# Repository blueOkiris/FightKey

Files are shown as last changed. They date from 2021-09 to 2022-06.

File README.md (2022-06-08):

# Fight Key

## Description

A keyboard-based fight stick

Image of New Physical Fight Key

Version 1:

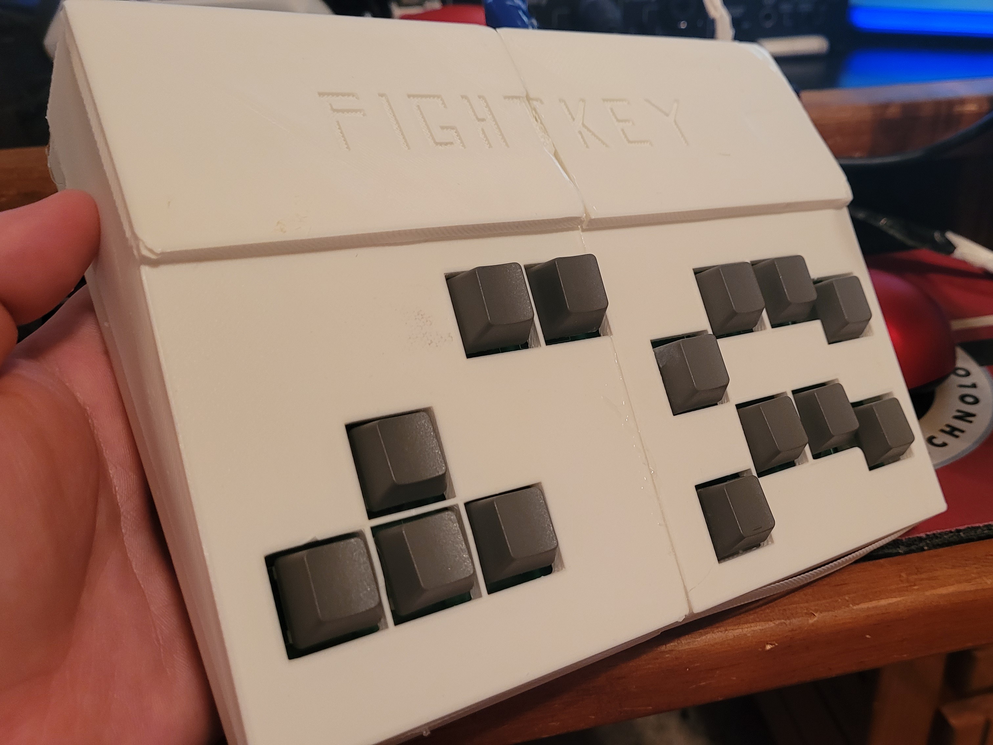
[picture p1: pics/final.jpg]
Image of Physical Fight Key


## Subdirectories

 - pcb - Fight Key KiCAD PCB project

 - pico - Code to upload to the pico within the Fight Key

 - enclosure - model for the 3D printed case for the Fight Key

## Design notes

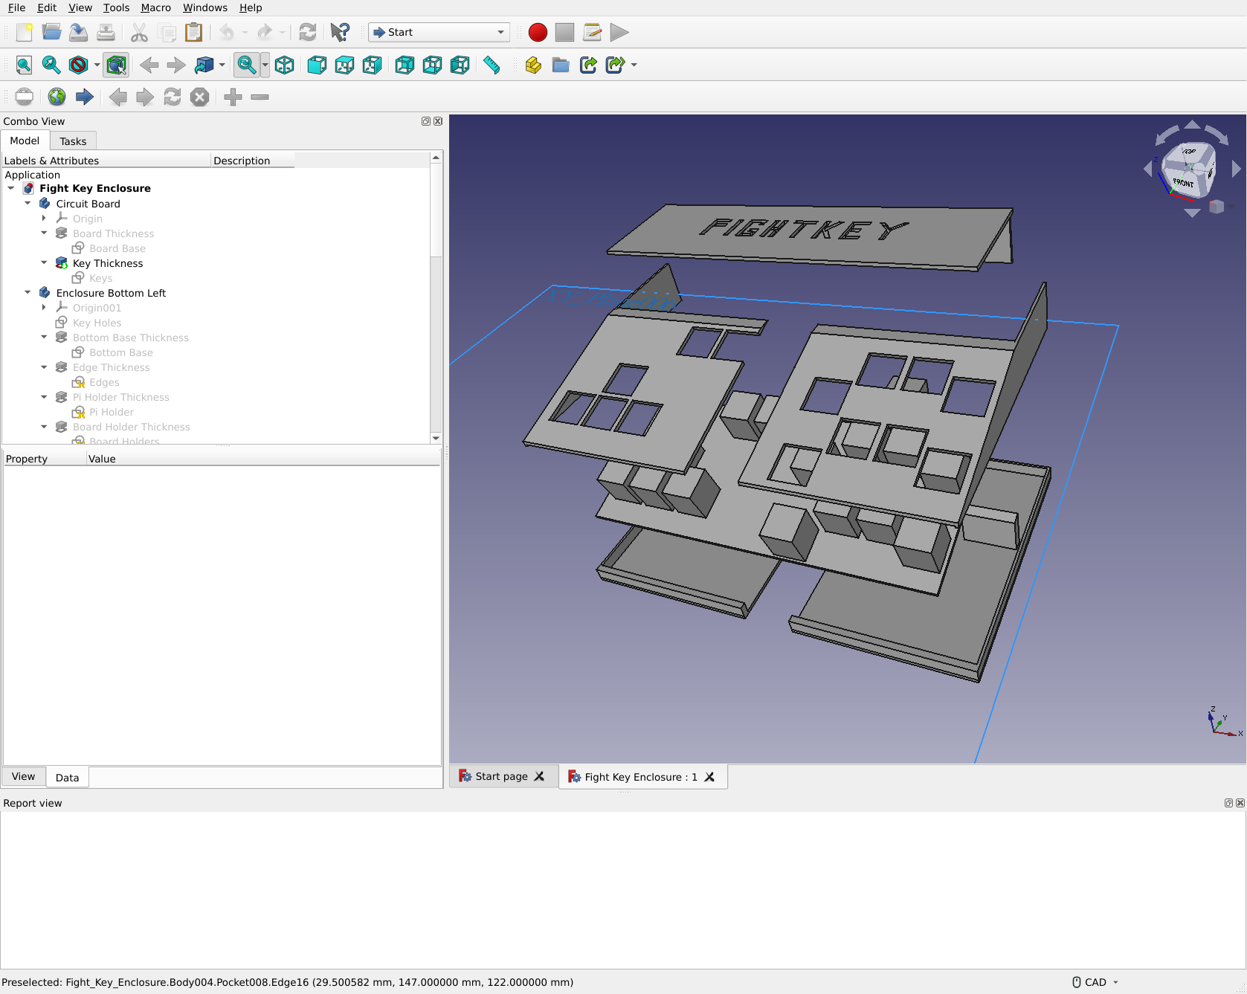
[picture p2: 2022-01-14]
pics/fight-key-model.png

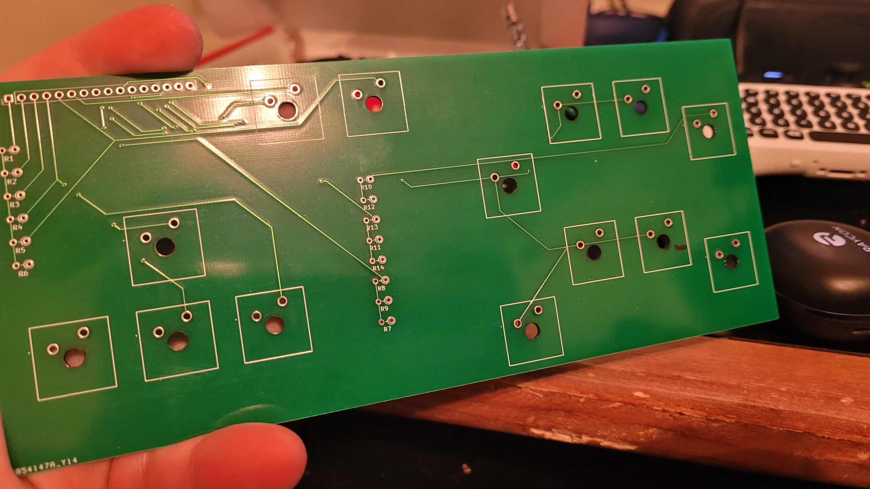
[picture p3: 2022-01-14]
pics/board.png

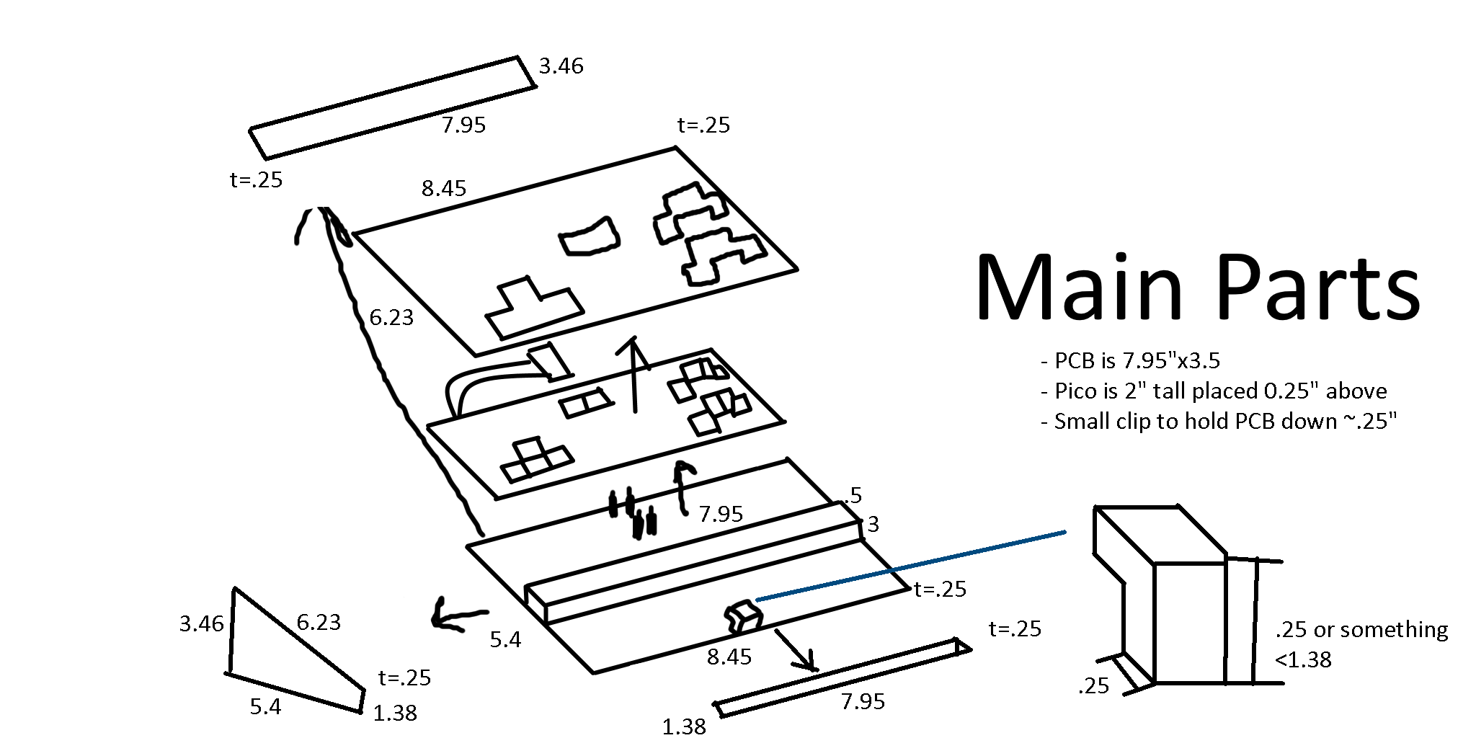
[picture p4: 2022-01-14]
enclosure/basic-idea.png

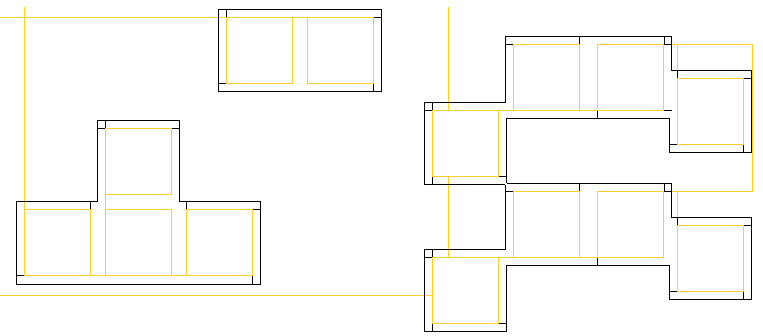
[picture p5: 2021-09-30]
enclosure/cut-out.png

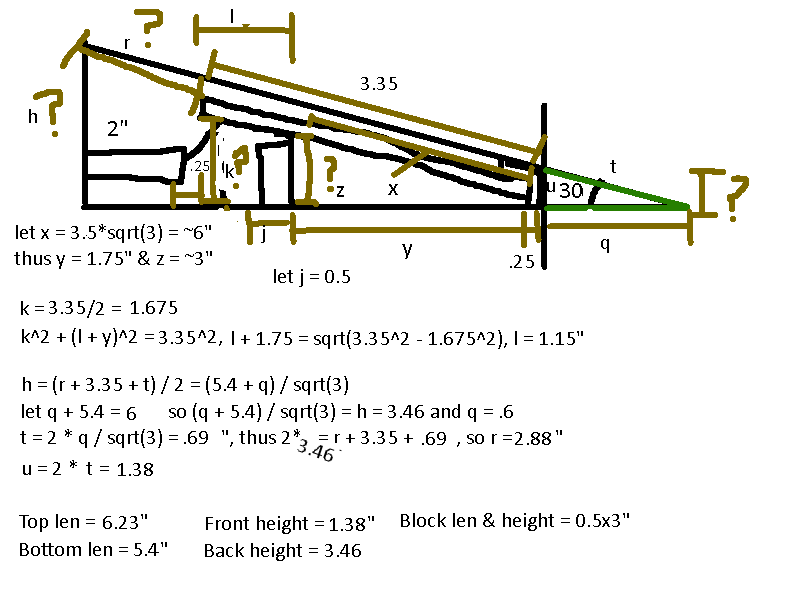
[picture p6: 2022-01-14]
enclosure/trig.png

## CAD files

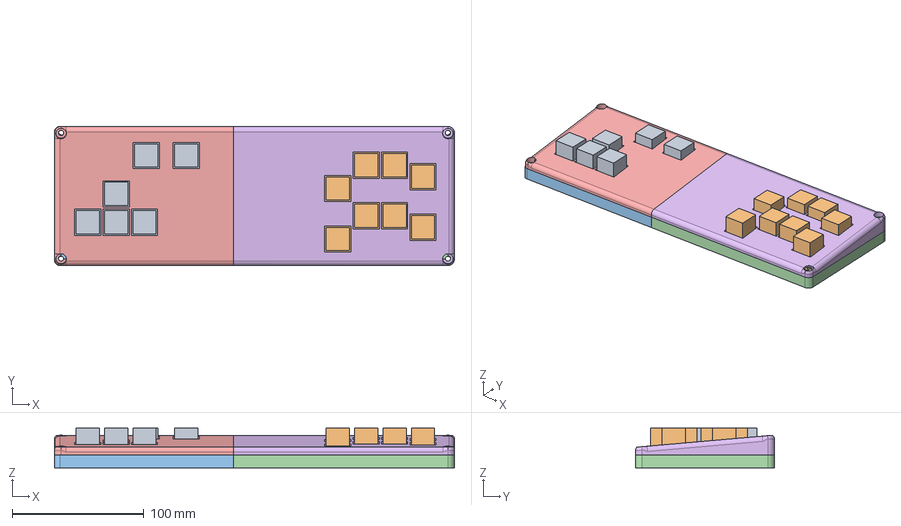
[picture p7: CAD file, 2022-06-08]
enclosure/Fight Key Enclosure.FCStd
304.0 x 105.7 x 30.3 mm
Left PCB Ref
Right PCB Ref
Left Enc Base
Right Enc Base
Left Enc Top
Right Enc Top

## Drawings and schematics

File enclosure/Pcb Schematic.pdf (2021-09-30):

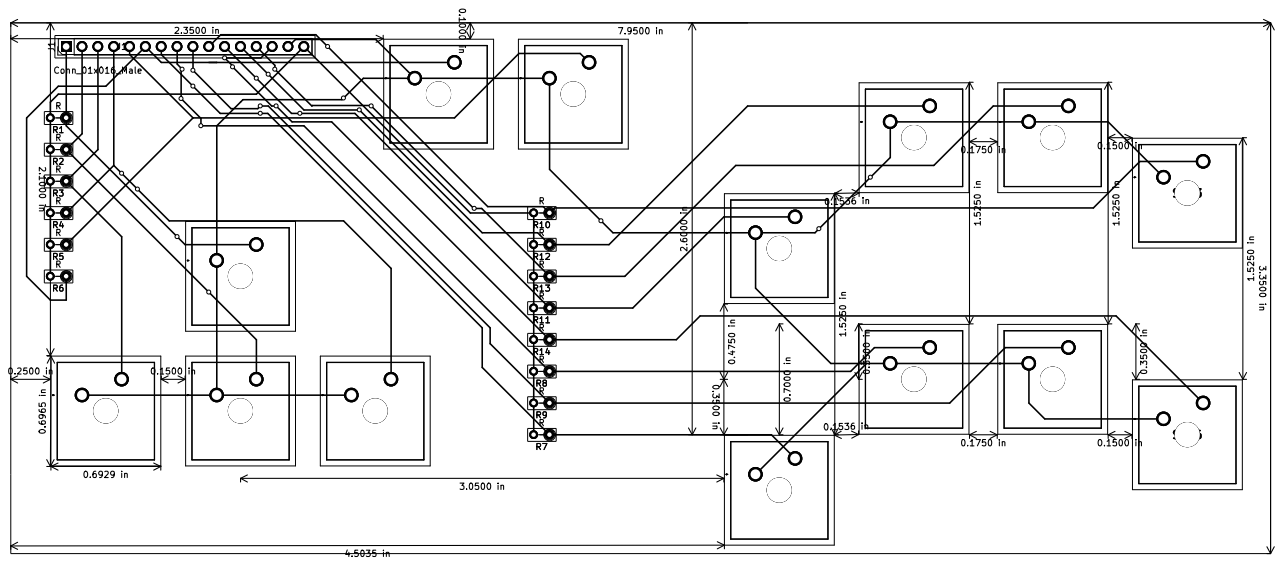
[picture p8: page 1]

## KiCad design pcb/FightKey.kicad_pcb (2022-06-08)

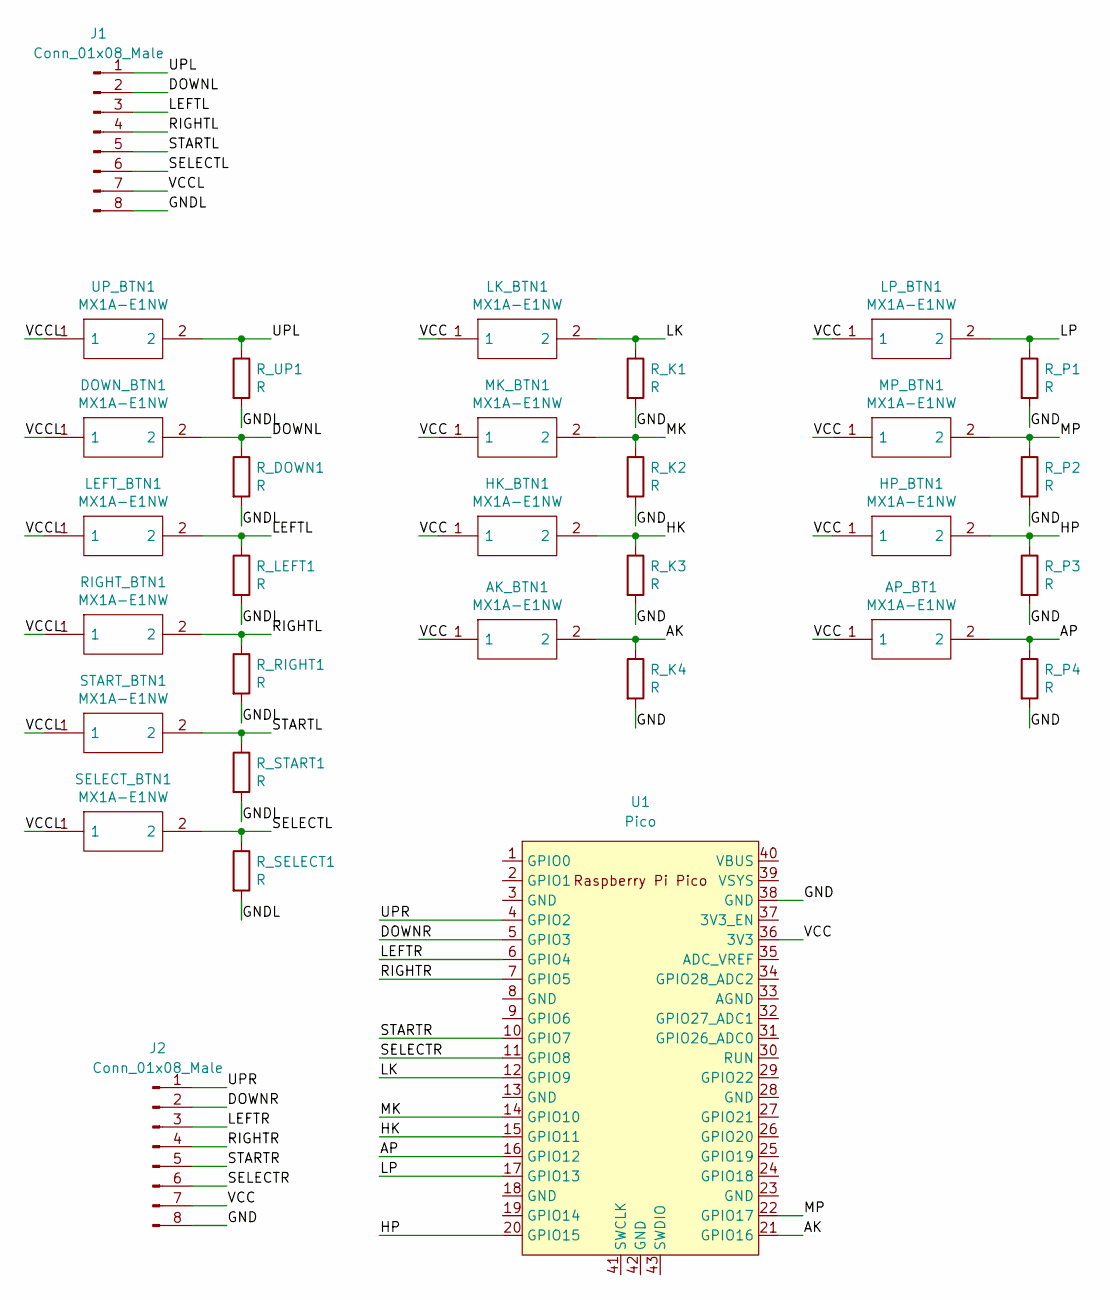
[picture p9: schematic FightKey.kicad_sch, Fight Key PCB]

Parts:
AK_BTN1: MX1A-E1NW; MX1AE1NW; Mouser Part Number 540-MX1A-E1NW
AP_BT1: MX1A-E1NW; MX1AE1NW; Mouser Part Number 540-MX1A-E1NW
DOWN_BTN1: MX1A-E1NW; MX1AE1NW; Mouser Part Number 540-MX1A-E1NW
HK_BTN1: MX1A-E1NW; MX1AE1NW; Mouser Part Number 540-MX1A-E1NW
HP_BTN1: MX1A-E1NW; MX1AE1NW; Mouser Part Number 540-MX1A-E1NW
J1, J2: Conn_01x08_Male; PinHeader_1x08_P2.54mm_Vertical
LEFT_BTN1: MX1A-E1NW; MX1AE1NW; Mouser Part Number 540-MX1A-E1NW
LK_BTN1: MX1A-E1NW; MX1AE1NW; Mouser Part Number 540-MX1A-E1NW
LP_BTN1: MX1A-E1NW; MX1AE1NW; Mouser Part Number 540-MX1A-E1NW
MK_BTN1: MX1A-E1NW; MX1AE1NW; Mouser Part Number 540-MX1A-E1NW
MP_BTN1: MX1A-E1NW; MX1AE1NW; Mouser Part Number 540-MX1A-E1NW
RIGHT_BTN1: MX1A-E1NW; MX1AE1NW; Mouser Part Number 540-MX1A-E1NW
R_DOWN1: R; R_Axial_DIN0204_L3.6mm_D1.6mm_P2.54mm_Vertical
R_K1, R_K2, R_K3, R_K4: R; R_Axial_DIN0204_L3.6mm_D1.6mm_P2.54mm_Vertical
R_LEFT1: R; R_Axial_DIN0204_L3.6mm_D1.6mm_P2.54mm_Vertical
R_P1, R_P2, R_P3, R_P4: R; R_Axial_DIN0204_L3.6mm_D1.6mm_P2.54mm_Vertical
R_RIGHT1: R; R_Axial_DIN0204_L3.6mm_D1.6mm_P2.54mm_Vertical
R_SELECT1: R; R_Axial_DIN0204_L3.6mm_D1.6mm_P2.54mm_Vertical
R_START1: R; R_Axial_DIN0204_L3.6mm_D1.6mm_P2.54mm_Vertical
R_UP1: R; R_Axial_DIN0204_L3.6mm_D1.6mm_P2.54mm_Vertical
SELECT_BTN1: MX1A-E1NW; MX1AE1NW; Mouser Part Number 540-MX1A-E1NW
START_BTN1: MX1A-E1NW; MX1AE1NW; Mouser Part Number 540-MX1A-E1NW
U1: Pico; RPi_Pico_SMD_TH
UP_BTN1: MX1A-E1NW; MX1AE1NW; Mouser Part Number 540-MX1A-E1NW

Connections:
/AK: AK_BTN1.2, R_K4.1, U1.21 (GPIO16)
/AP: AP_BT1.2, R_P4.1, U1.16 (GPIO12)
/DOWNL: DOWN_BTN1.2, J1.2, R_DOWN1.1
/DOWNR: J2.2, U1.5 (GPIO3)
/GND: J2.8, R_K1.2, R_K2.2, R_K3.2, R_K4.2, R_P1.2, R_P2.2, R_P3.2, R_P4.2, U1.38 (GND)
/GNDL: J1.8, R_DOWN1.2, R_LEFT1.2, R_RIGHT1.2, R_SELECT1.2, R_START1.2, R_UP1.2
/HK: HK_BTN1.2, R_K3.1, U1.15 (GPIO11)
/HP: HP_BTN1.2, R_P3.1, U1.20 (GPIO15)
/LEFTL: J1.3, LEFT_BTN1.2, R_LEFT1.1
/LEFTR: J2.3, U1.6 (GPIO4)
/LK: LK_BTN1.2, R_K1.1, U1.12 (GPIO9)
/LP: LP_BTN1.2, R_P1.1, U1.17 (GPIO13)
/MK: MK_BTN1.2, R_K2.1, U1.14 (GPIO10)
/MP: MP_BTN1.2, R_P2.1, U1.22 (GPIO17)
/RIGHTL: J1.4, RIGHT_BTN1.2, R_RIGHT1.1
/RIGHTR: J2.4, U1.7 (GPIO5)
/SELECTL: J1.6, R_SELECT1.1, SELECT_BTN1.2
/SELECTR: J2.6, U1.11 (GPIO8)
/STARTL: J1.5, R_START1.1, START_BTN1.2
/STARTR: J2.5, U1.10 (GPIO7)
/UPL: J1.1, R_UP1.1, UP_BTN1.2
/UPR: J2.1, U1.4 (GPIO2)
/VCC: AK_BTN1.1, AP_BT1.1, HK_BTN1.1, HP_BTN1.1, J2.7, LK_BTN1.1, LP_BTN1.1, MK_BTN1.1, MP_BTN1.1, U1.36 (3V3)
/VCCL: DOWN_BTN1.1, J1.7, LEFT_BTN1.1, RIGHT_BTN1.1, SELECT_BTN1.1, START_BTN1.1, UP_BTN1.1

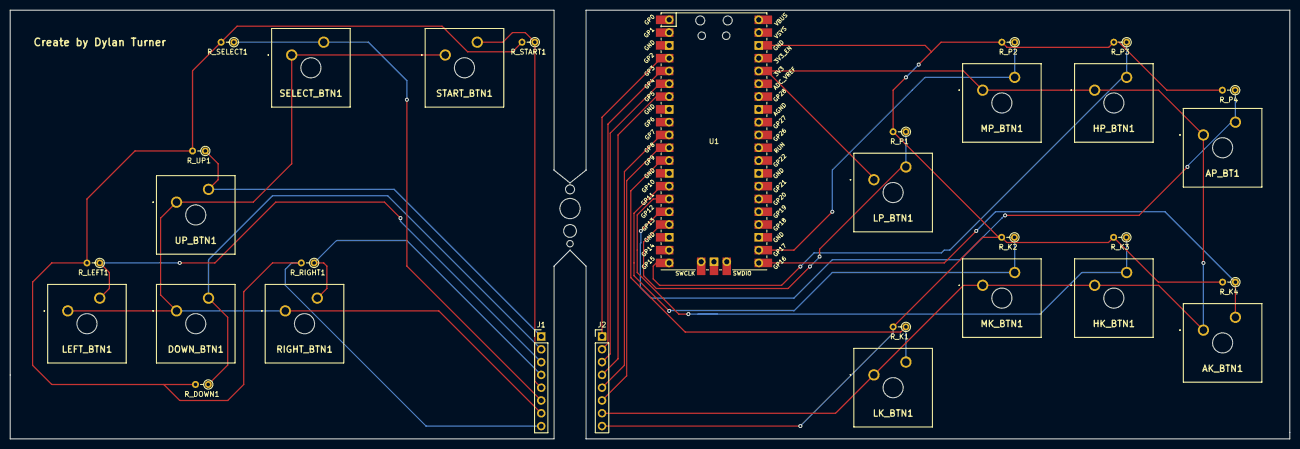
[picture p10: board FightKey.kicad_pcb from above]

Board: 2 copper layers, 254.0 x 85.1 mm, 31 parts (0 on the bottom side), 24 nets.

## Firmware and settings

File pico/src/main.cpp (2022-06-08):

/*
 * Author: Dylan Turner
 * Description: Entry point for Keyboard system
 */

#include <stdio.h>
#include <stdlib.h>
#include <pico/stdlib.h>
#include <bsp/board.h>
#include <hardware/vreg.h>
#include <map>
#include <vector>
#include <memory>
#include <Buttons.hpp>
#include <Controller.hpp>
#include <Hid.hpp>

using namespace fightkey;

const std::map<Button, uint> g_btnMapping = {
    { Button::Up,           2 },
    { Button::Down,         3 },
    { Button::Left,         4 },
    { Button::Right,        5 },
    { Button::Start,        7 },
    { Button::Select,       8 },
    { Button::LightKick,    9 },
    { Button::MediumKick,   10 },
    { Button::HeavyKick,    15 },
    { Button::AllKick,      12 },
    { Button::LightPunch,   13 },
    { Button::MediumPunch,  17 },
    { Button::HeavyPunch,   11 },
    { Button::AllPunch,     16 }
};
const std::map<Button, uint8_t> g_keyMapping = {
    { Button::Up,           HID_KEY_ARROW_UP },
    { Button::Down,         HID_KEY_ARROW_DOWN },
    { Button::Left,         HID_KEY_ARROW_LEFT },
    { Button::Right,        HID_KEY_ARROW_RIGHT },
    { Button::Start,        HID_KEY_ENTER },
    { Button::Select,       HID_KEY_ESCAPE },
    { Button::LightPunch,   HID_KEY_1 },
    { Button::MediumPunch,  HID_KEY_2 },
    { Button::HeavyPunch,   HID_KEY_3 },
    { Button::AllPunch,     HID_KEY_4 },
    { Button::LightKick,    HID_KEY_5 },
    { Button::MediumKick,   HID_KEY_6 },
    { Button::HeavyKick,    HID_KEY_7 },
    { Button::AllKick,      HID_KEY_8 }
};

const int pressToReleaseDelay = 30; // Minimum press down before an up registers

void readButtonsSendKeys(void); // Primary functionality
void testHid(void);
void testButton(const Button btnToTest);

int main(void) {
    // Speed up clock
    set_sys_clock_khz(270000, true);

    readButtonsSendKeys();
    //testHid();
    //testButton(Button::Up);

    return 0;
}

void readButtonsSendKeys(void) {
    const GpioController controller(g_btnMapping);
    //HidKeyboard keyboard(g_keyMapping);
    HidGamepad gamepad;
    
    while(1) {
        //keyboard.update();
        gamepad.update();

        const auto btnState = controller.state();
        for(const auto &btnStatePair : btnState) {
            if(btnStatePair.second) {
                //keyboard.pressKey(btnStatePair.first);
                gamepad.pressButton(btnStatePair.first);
            } else {
                //keyboard.releaseKey(btnStatePair.first);
                gamepad.releaseButton(btnStatePair.first);
            }
        }
    }
}

void keyboardPressAndReleaseKey(const Button btn, HidKeyboard &keyboard) {
    keyboard.pressKey(btn);
    keyboard.update();
    keyboard.delayMs(pressToReleaseDelay);
    keyboard.releaseKey(btn);
    keyboard.update();
    keyboard.delayMs(pressToReleaseDelay);
}

void testHid(void) {
    HidKeyboard keyboard(g_keyMapping);
    
    while(1) {
        keyboardPressAndReleaseKey(Button::Down, keyboard);
        keyboardPressAndReleaseKey(Button::Right, keyboard);
        keyboardPressAndReleaseKey(Button::Down, keyboard);
        keyboardPressAndReleaseKey(Button::Right, keyboard);
        keyboardPressAndReleaseKey(Button::LightKick, keyboard);

        keyboard.delayMs(1000);
    }
}

void testButton(const Button btnToTest) {
    const GpioController controller(g_btnMapping);
    
    gpio_init(PICO_DEFAULT_LED_PIN);
    gpio_set_dir(PICO_DEFAULT_LED_PIN, GPIO_OUT);

    while(1) {
        const auto btnState = controller.state();
        gpio_put(PICO_DEFAULT_LED_PIN, btnState.at(btnToTest));
    }
}

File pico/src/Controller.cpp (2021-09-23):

/*
 * Author: Dylan Turner
 * Description: Implementation of a controller to read from
 */

#include <map>
#include <memory>
#include <stdio.h>
#include <pico/stdlib.h>
#include <Buttons.hpp>
#include <Controller.hpp>

using namespace fightkey;

GpioController::GpioController(const std::map<Button, uint> &btnMapping) :
        _btnMapping(btnMapping) {
    _initPins();
}

std::map<Button, bool> GpioController::state(void) const {
    std::map<Button, bool> curState;
    for(const auto &btnPinPair : _btnMapping) {
        curState.insert(std::make_pair(
            btnPinPair.first, gpio_get(btnPinPair.second)
        ));
    }
    return curState;
}

void GpioController::_initPins(void) const {
    for(const auto &btnPinPair : _btnMapping) {
        gpio_init(btnPinPair.second);
        gpio_set_dir(btnPinPair.second, false);
    }
}

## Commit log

2021-09-22 Added current model work and pcb design
    [Enclosure.blend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]
2021-09-22 Added code from old version of Game Card (to reuse pico hid stuff
2021-09-23 Adjusted project to get closer to correct format
    [FightKey.kicad_pcb, FightKey.sch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]
2021-09-23 Fixed naming convention
    [enclosure.blend]
2021-09-23 Added button test to verify button functionality.
2021-09-23 Flipped kicks and punches to match pcb
    [main.cpp]
2021-09-30 Changed medium punch bc I broke the pin
    [main.cpp]
2021-09-30 Fixed makefile and removed uneeded code
    [main.cpp]
2021-09-30 Added basic idea for enclosure as well as diagram that can be printed out and used to cut out the front panel
2022-01-14 Added enclosure and final picture
    [Fight Key Enclosure.FCStd, FightKey - Bottom Left.stl, FightKey - Bottom Right.stl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]
2022-01-14 Removed stl files from being added
2022-01-14 Actually removed models
    [FightKey - Bottom Left.stl, FightKey - Bottom Right.stl, FightKey - Top Left.stl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]
2022-01-14 Removed old blender model
    [enclosure.blend]
2022-03-08 Switched to gamepad version
2022-03-08 Fixed controller button mapping
    [main.cpp]
2022-06-08 Converted to slimmer, openable model with split design (#1)
    * Remade PCB to be split and include Pico in design
    * Removed stray trace
    * Restarted enclosure and modeled out new board left side as a reference
    * Fixed missing connection (will have to hotwire physically :(
    * Added bottom of enclosure (not done) and modeled right pcb board
    * Added top-left of enclosure, left-side rounding, and screw holes
    * Added top-right and fixed minor issues. Design complete
    * Fixed the keybindings to match expected
    * Turned off sys clock increase as it seems to break new pico for some reason
    * Readded overclocking, but a decreased amount
    * Reworked model polish (screw holes and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
    [Fight Key Enclosure.FCStd, FightKey.kicad_pcb, FightKey.kicad_sch]
